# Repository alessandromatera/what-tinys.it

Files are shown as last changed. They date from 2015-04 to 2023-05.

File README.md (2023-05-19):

# "What Tinys.it?"
### A 3D printed LED watch with Atmega328P microcontroller programmed with Arduino

#### The Story
I wanted to build a LED watch with Arduino but, searching on the web, i could not find what i was looking for. So I've decided to build my own.
I wanted to use Attiny85 microcontroller from my board [Tinys](http://www.tinys.it/) but it has only few I/O and can't be used to drive many LEDs. So i decided to use an Atmega328P (the same micro of Arduino UNO board) in TQFP package with 32 pin.

For perfect timing i've used a 32.768 KHz Crystal connected to Xtal pins of Atmega328p running in asynchronous mode. In this way i can use internal 8Mhz oscillator as main clock of the microcontroller and the overflow of timer2 (used for the external crystal) as interrupt for increase the seconds.

Why 32.768Khz Crystal? Because using prescaler to 128 we have 256 Hz, so 1 overflow/sec. It's the most used crystal for watches for this reason.

What about the name? Well, my web site is [Tinys.it](http://www.tinys.it/) :D

#### The Project
I wanted to build a watch with 60 LEDs but to keep the clock size small, i've decide to use only 32 LED (1 LED/100 seconds). But even if the microcontroller has 32 pin, they aren't all I/O: only 25 pins can be used for the 32 LEDs and the button. To drive a larger number of LEDs with few pins i've used the [Charlieplexing Matrix](http://en.wikipedia.org/wiki/Charlieplexing), in this way i can drive 6 LEDs with only 3 Pins. Becouse i can't use two different color of LEDs, to distinguish between hours and minutes, the minutes LED is blinking. 

To reduce battery drain the watch is always in sleep. To show-up the time is needed to press the button.

As the clock hands, the hours LED isn't stay in the same position: is moving a bit, consequently to minutes.

The watch is powered by a 3 Volt CR2032 battery. With this battery the LEDs resistors can be shorted.

#### The Firmware
After setup the timer2 overflow interrupt and the button change-pin interrupt, the microcontroller goes to sleep. Every time the timer2 goes overflow (1 overflow/seconds) the microcontroller wakes up and increase the seconds. 

When the button is pressed for a small period of time, the button's interrupt occur and the time is show up. Instead, if the button is pressed for two seconds, we entering in programming mode, where we can set the time: after all LEDs are turned on, we can release the button and the current hours LED is turned on. Pressing one time the button hours change to the next. To record the current hours you need to press the button for about 2 seconds. After the hours LED is switched off, release the button and the minutes LED is turned on. Like the hours LED push the button to choose the right minutes and then long press to record the minutes. After the minutes LED is turned off, all LEDs is turned on. The corrected time is show up.

#### Upload the sketch
To Upload the firmware i use avr in Mac terminal and an Arduino UNO as ISP programmer. 

To do that follow these steps:

1. Connect the Arduino UNO board to PC or Mac.
2. Select the `ArduinoISP` sketch from `File -> Examples`
3. Upload the sketch to the Arduino UNO board
4. Open the watch sketch
5. Compile the sketch using Arduino IDE
6. Connect the SPI watch pins to Arduino UNO pins in this way:
	* Watch PIN `Reset - JP6` to Arduino PIN `10`
	* Watch PIN `11 - JP3` to Arduino PIN `11`
	* Watch PIN `12 - JP4` to Arduino PIN `12`
	* Watch PIN `13 - JP5` to Arduino PIN `13`
	* Watch PIN `V+ - JP1` to Arduino PIN `+3.3V`
	* Watch PIN `GND - JP2` to Arduino PIN `GND`
7. On Mac terminal (i think is similar for Windows/Linux users) write this
	```
	avrdude -v -v -v -v -cstk500v1 -pm328p  -P/dev/tty.usbmodemfa131 -b19200 -D -e -Ulock:w:0x3F:m -Uefuse:w:0x07:m -Uhfuse:w:0xDE:m -Ulfuse:w:0xE2:m -Uflash:w:/path/of/your/hex/file.hex:i
	```
	
	where:
	 - `tty.usbmodemfa131` is the serial port of Arduino board
	 - `/path/of/your/hex/file.hex` is the path of `.hex` file that can be taken from the Arduino IDE enabling `verbose output` from `Preferences -> Show Verbose output during: -> compilation`
	
All this stuff because i wanted to program the board using SPI not using Arduino bootloader. I Think that the watch can be programmed like an Arduino UNO using the `breadboard 8Mhz internal oscillator` bootloader and soldering two wires to pin `0` and `1` of the watch, but i've not tried it.

I've have used fuses for disabling `BOD` so you need to modify the bootloader of Arduino to do this. (Maybe you can do this in sketch?).

#### The Case
The 3D printed case was realized by my brother Andrea Matera.

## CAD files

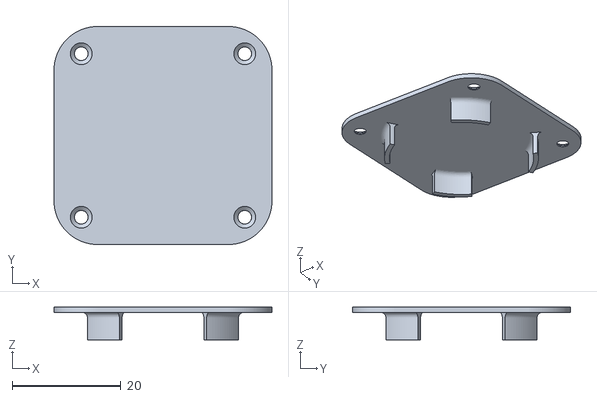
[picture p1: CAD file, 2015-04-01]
Case/tappo.stl
40.0 x 40.0 x 6.00

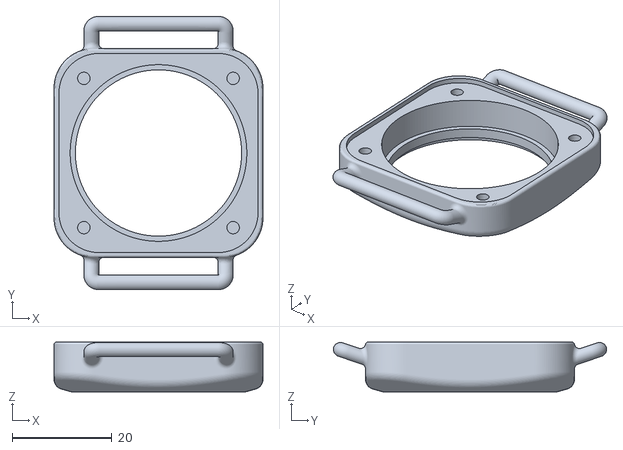
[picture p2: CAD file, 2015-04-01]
Case/Body.stl
42.0 x 54.9 x 10.0

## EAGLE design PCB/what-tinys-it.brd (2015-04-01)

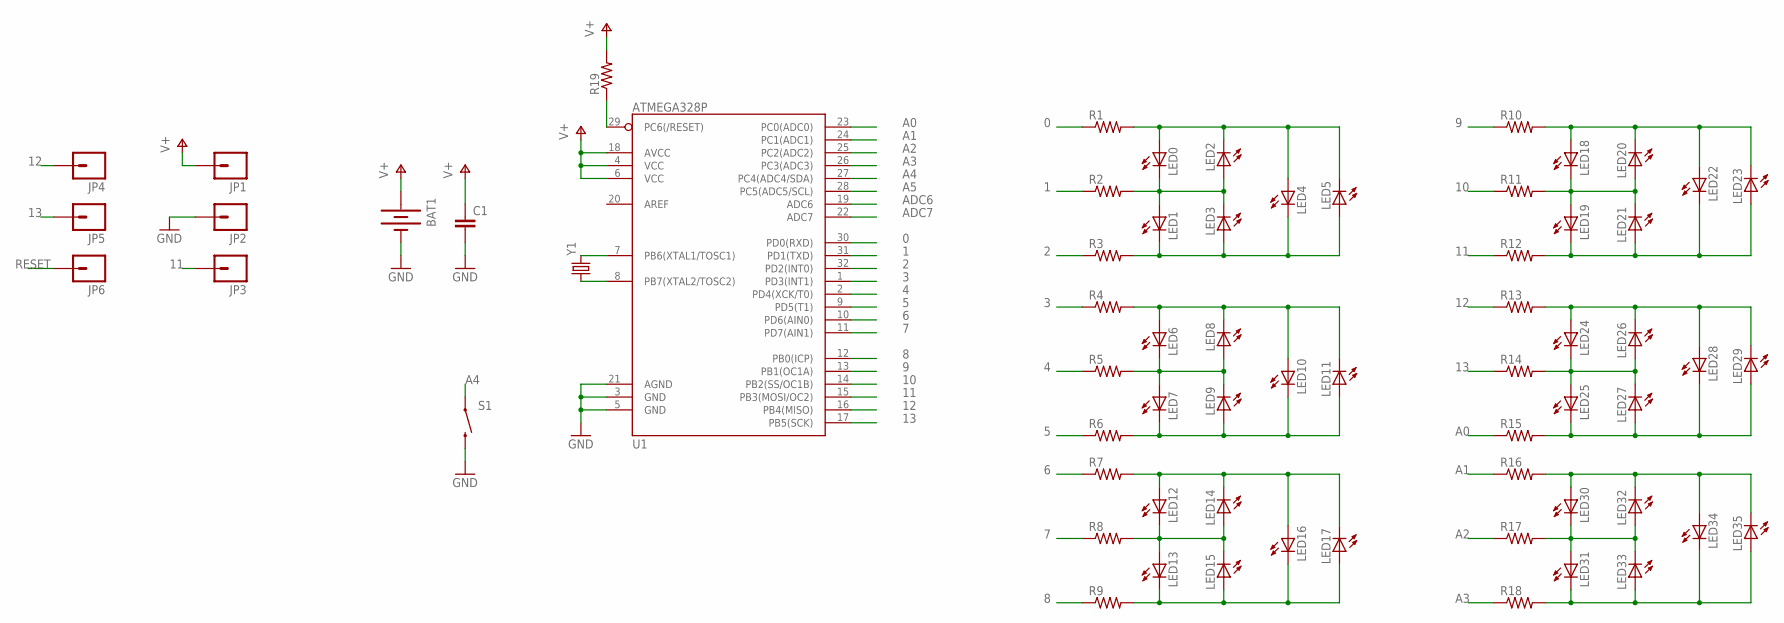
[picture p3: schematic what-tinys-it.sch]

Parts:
BAT1: BATTERY20SMD; BATTCON_20MM
C1: C-EUC0805; C0805
JP1, JP2, JP3, JP4, JP5, JP6: M01SMDNS; 1X01NS
LED0, LED1, LED2, LED3, LED4, LED5, LED6, LED7, LED8, LED9, LED10, LED11, LED12, LED13, LED14, LED15, LED16, LED17, LED18, LED19, LED20, LED21, LED22, LED23, LED24, LED25, LED26, LED27, LED28, LED29, LED30, LED31, LED32, LED33, LED34, LED35: LEDCHIPLED_0805; CHIPLED_0805
R1, R2, R3, R4, R5, R6, R7, R8, R9, R10, R11, R12, R13, R14, R15, R16, R17, R18, R19: RESISTOR0805-RES; 0805
S1: SWITCH-MOMENTARY-2SMD-3; TACTILE_SWITCH_SMD-3
U1: ATMEGA328P; TQFP32-08
Y1: CRYSTAL32-SMD; CRYSTAL-32KHZ-SMD

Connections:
0: R1.1, U1.30 (PD0(RXD))
1: R2.1, U1.31 (PD1(TXD))
2: R3.1, U1.32 (PD2(INT0))
3: R4.1, U1.1 (PD3(INT1))
4: R5.1, U1.2 (PD4(XCK/T0))
5: R6.1, U1.9 (PD5(T1))
6: R7.1, U1.10 (PD6(AIN0))
7: R8.1, U1.11 (PD7(AIN1))
8: R9.1, U1.12 (PB0(ICP))
9: R10.1, U1.13 (PB1(OC1A))
10: R11.1, U1.14 (PB2(SS/OC1B))
11: JP3.1, R12.1, U1.15 (PB3(MOSI/OC2))
12: JP4.1, R13.1, U1.16 (PB4(MISO))
13: JP5.1, R14.1, U1.17 (PB5(SCK))
A0: R15.1, U1.23 (PC0(ADC0))
A1: R16.1, U1.24 (PC1(ADC1))
A2: R17.1, U1.25 (PC2(ADC2))
A3: R18.1, U1.26 (PC3(ADC3))
A4: S1.1, U1.27 (PC4(ADC4/SDA))
A5: U1.28 (PC5(ADC5/SCL))
ADC6: U1.19 (ADC6)
ADC7: U1.22 (ADC7)
GND: BAT1.2 (-), C1.2, JP2.1, S1.4 (2), U1.3 (GND), U1.5 (GND), U1.21 (AGND)
unnamed: LED0.A, LED2.C, LED4.A, LED5.C, R1.2
unnamed: LED6.A, LED8.C, LED10.A, LED11.C, R4.2
unnamed: LED0.C, LED1.A, LED2.A, LED3.C, R2.2
unnamed: LED1.C, LED3.A, LED4.C, LED5.A, R3.2
unnamed: LED12.A, LED14.C, LED16.A, LED17.C, R7.2
unnamed: LED6.C, LED7.A, LED8.A, LED9.C, R5.2
unnamed: LED7.C, LED9.A, LED10.C, LED11.A, R6.2
unnamed: LED18.A, LED20.C, LED22.A, LED23.C, R10.2
unnamed: LED12.C, LED13.A, LED14.A, LED15.C, R8.2
unnamed: LED13.C, LED15.A, LED16.C, LED17.A, R9.2
unnamed: LED18.C, LED19.A, LED20.A, LED21.C, R11.2
unnamed: LED24.A, LED26.C, LED28.A, LED29.C, R13.2
unnamed: LED19.C, LED21.A, LED22.C, LED23.A, R12.2
unnamed: LED24.C, LED25.A, LED26.A, LED27.C, R14.2
unnamed: LED30.A, LED32.C, LED34.A, LED35.C, R16.2
unnamed: U1.7 (PB6(XTAL1/TOSC1)), Y1.X2 (2)
unnamed: LED25.C, LED27.A, LED28.C, LED29.A, R15.2
unnamed: U1.8 (PB7(XTAL2/TOSC2)), Y1.X1 (1)
unnamed: LED30.C, LED31.A, LED32.A, LED33.C, R17.2
unnamed: LED31.C, LED33.A, LED34.C, LED35.A, R18.2
RESET: JP6.1, R19.1, U1.29 (PC6(/RESET))
V+: BAT1.1 (+), C1.1, JP1.1, R19.2, U1.4 (VCC), U1.6 (VCC), U1.18 (AVCC)

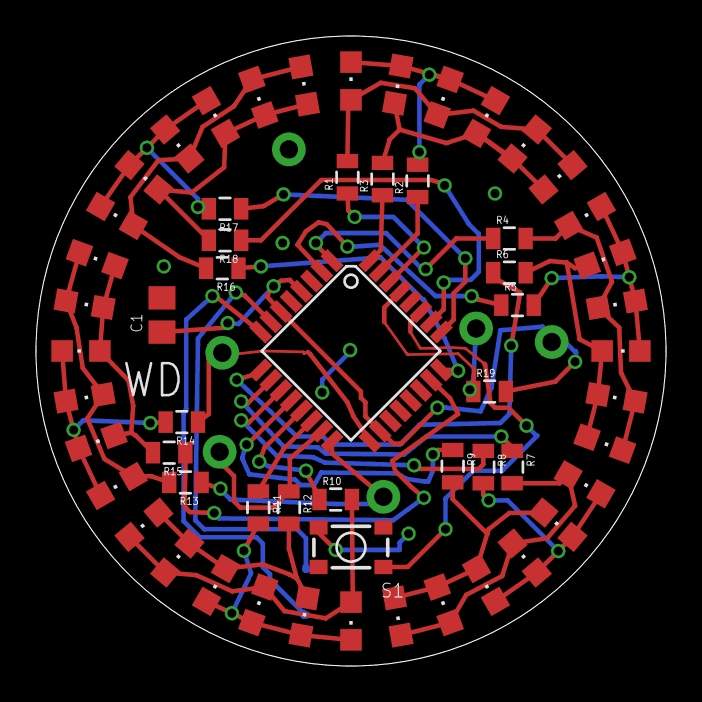
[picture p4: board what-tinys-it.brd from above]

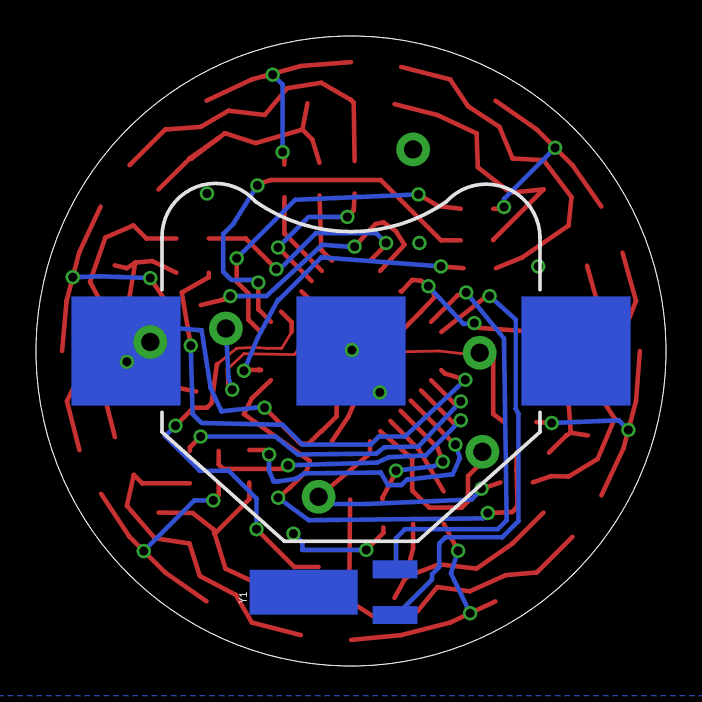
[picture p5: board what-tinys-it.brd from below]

Board: 2 copper layers, 35.0 x 35.0 mm, 66 parts (3 on the bottom side), 42 nets.

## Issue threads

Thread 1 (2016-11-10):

compiling errr

starsx2016, 2016-11-10:
Arduino : 1.6.12 (Mac OS X), Carte : "Arduino Duemilanove or Diecimila, ATmega328"

/Users/starsx/Dropbox/project/what-tinys.it-master/firmware/WhatTinysIt_v_1/WhatTinysIt_v_1.ino: In function 'void setup()':
WhatTinysIt_v_1:49: error: 'button' was not declared in this scope
   pinMode(button, INPUT);
           ^
/Users/starsx/Dropbox/project/what-tinys.it-master/firmware/WhatTinysIt_v_1/WhatTinysIt_v_1.ino: In function 'void loop()':
WhatTinysIt_v_1:77: error: 'button' was not declared in this scope
     while(!digitalRead(button)){
                        ^
/Users/starsx/Dropbox/project/what-tinys.it-master/firmware/WhatTinysIt_v_1/WhatTinysIt_v_1.ino: In function 'void setClock()':
WhatTinysIt_v_1:156: error: 'button' was not declared in this scope
   while(!digitalRead(button)){
                      ^
WhatTinysIt_v_1:178: error: 'button' was not declared in this scope
     while(!digitalRead(button)){
                        ^
WhatTinysIt_v_1:199: error: 'button' was not declared in this scope
       while(!digitalRead(button)){
                          ^
WhatTinysIt_v_1:212: error: 'button' was not declared in this scope
     while(!digitalRead(button)){
                        ^
WhatTinysIt_v_1:231: error: 'button' was not declared in this scope
       while(!digitalRead(button)){
                          ^
exit status 1
'button' was not declared in this scope

alessandromatera, 2016-11-10:
Try this:

At the top of the sketch, after define declarations, write:

Int button = A4;

Instead
#define A4 button

starsx2016, 2016-11-10:
thank you

Closed 2023-05-19.

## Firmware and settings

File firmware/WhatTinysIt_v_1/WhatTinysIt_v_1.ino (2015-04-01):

#include <avr/sleep.h>
#include <avr/power.h>
#include <avr/interrupt.h>

#define A4 button

unsigned int seconds = 0;
unsigned int hours = 0;

boolean button_interrupt = false; //boolean to let you know when interrupt button is occurred

int setupPeriod = 2; //hold down button for this period in seconds to enter in programming mode

//overflow interrupt from 32.768Khz Crystal every 1 sec
ISR(TIMER2_OVF_vect){
  //increase the seconds
  seconds++;
  //if seconds is over 3600, we increase the hours
  if (seconds > 3600) {
    seconds = 0;
    hours++;
    //if hours is over 11 come back to zero
    if (hours > 11) {
      hours = 0;
    }
  }
}

//pin-change interrupt from button
ISR(PCINT1_vect){
  //disable interrupt button to not start another interrupt
  bitClear(PCMSK1,PCINT12);
  button_interrupt = true;
}


void setup() {
  TIMSK2  = 0; //stop timer interrupt
  TCCR2A = 0; // this stops the timer
  TCCR2B = 0;  // this stops the timer
  TCNT2 = 0;  // reset the timer2 counter

  //Enable asynchronous mode
  bitSet(ASSR, AS2); //set TMR2 to work in asynchronous mode
  TCCR2B = bit(CS22) | bit(CS20); // prescaler 128 -> 256 Hz = 1 overflow/sec
  bitSet(TIMSK2, TOIE2); //eable overflow interrupt for tmr2

    //setup pin-change interrupt for button
  pinMode(button, INPUT);
  digitalWrite(button, HIGH);//enable pullup resistor
  bitSet(PCMSK1,PCINT12); //enable pinchange for pin A4
  bitSet(PCICR,PCIE1); //enable interrupt button

  //disabling all unnecessary peripherals to reduce power
  ADCSRA &= ~bit(ADEN); //disable ADC
  power_adc_disable(); // disable ADC converter
  power_spi_disable(); // disable SPI
  power_usart0_disable();// disable Serial (USART)
  power_timer1_disable();// disable Timer 1
  power_twi_disable(); // disable TWI (I2C)

}

void loop() {
  //if we press the button the pin-change interrupt occur
  //then if we fast press the button show up the time
  //else, if we press the button for "setupPeriod" seconds we
  //enter in programming mode and then set the time
  if (button_interrupt){
    button_interrupt = false; //resetting our boolean flag
    
    //store and calculating the pressing time of the button
    int oldSeconds = seconds;
    int buttonSeconds = 0;
    
    //while the button is pressed we count the pressing time
    while(!digitalRead(button)){
      buttonSeconds = seconds-oldSeconds;
      if (buttonSeconds > setupPeriod){ //if we have pressed for over setupPeriod seconds
        setClock();  //enter in programming mode
      }
    }
    
    //show up the time
    showTime();

    bitSet(PCMSK1,PCINT12); //enable interrupt button
  }

  goSleep(); //go power save
}


void showTime(){

  int showPeriod = 4000; //showing time period in milliseconds
  int blinkingPeriod = 500; //blinking period for minutesLED in milliseconds

  int hoursLED = calculateHoursLED(hours, seconds);
  int minutesLED = calculateMinutesLED(seconds);

  //animation light game
  int oldSeconds = seconds;
  int i_led_game = hoursLED+1;
  if (i_led_game > 35)
    i_led_game = 0;
  boolean minutesLEDfired = false;
  unsigned long previouosMillis_animation = millis();
  while(i_led_game != hoursLED){
    changeLED(hoursLED, 1); //turn On hours LED
    changeLED(hoursLED, 0); //turn off hoursLED for multiplexing

    changeLED(i_led_game, 1); //turn on game LED
    changeLED(i_led_game, 0);

    //if LED game pass on minutes LED turn on minutesLED and stay on
    if(i_led_game == minutesLED || minutesLEDfired){ 
      minutesLEDfired = true;
      changeLED(minutesLED, 1); //turn On minutes LED
      changeLED(minutesLED, 0);
    }

    if ((millis() - previouosMillis_animation) > 10){ //every 10 ms change the game LED
      previouosMillis_animation = millis();
      i_led_game++;
      if (i_led_game > 35)
        i_led_game = 0;
    }
  }


  unsigned long currentMillis = millis();
  unsigned long previousMillis = currentMillis;
  unsigned long previousMillis_blinking = currentMillis;
  boolean minutesLEDstate = true;

  //show-up hours and seconds
  while ((millis() - previousMillis) < showPeriod) {

    changeLED(hoursLED, 1); //turn On hours LED
    changeLED(hoursLED, 0); //turn Off hours LED
    if ((millis() - previousMillis_blinking) >= blinkingPeriod) { //blink minute LED
      previousMillis_blinking = millis();
      minutesLEDstate = !minutesLEDstate;
    }
    changeLED(minutesLED, minutesLEDstate); //turn On/Off minutes LED
    changeLED(minutesLED, 0); //turn Off minutes LED
  }
}

//change hours and minutes -> programming mode
void setClock(){

  //while the button is pressed we turn on all LED
  //to let you know that we are in programming mode
  while(!digitalRead(button)){
    for (int i = 0; i <36; i++){
      changeLED(i, 1);
      changeLED(i, 0);
    }
  }


  int oldSeconds = seconds; //variable for button timing

  boolean hourSetted = false; //boolean for exit hours programming mode
  int hoursToSet = hours; //store hours
  if (seconds>=3550) //if seconds is higher than 3550 we turn on next hour because LED 0 is turned on
    hoursToSet++;
  int hoursLED = calculateHoursLED(hoursToSet, 0); //calculatin which hoursLED need to turnON
  changeLED(hoursLED, 1); //turn on the hoursLED
  while(!hourSetted){ //while hours are not setted
    boolean buttonPressed = false;
    oldSeconds = seconds;

    //if we press the button for small period of time, we change the hours
    //if we press for long time (setupPeriod) we set the hours and then go to setting minutes
    while(!digitalRead(button)){ 
      buttonPressed = true;
      delay(100);
      int buttonSeconds = seconds-oldSeconds;
      //setting hours
      if (buttonSeconds > setupPeriod){
        hourSetted = true;
        changeLED(hoursLED, 0);
        hours = hoursToSet; //set the hours
        while(!digitalRead(button)){
        }
      }
    }
    //changing hours
    if (!hourSetted && buttonPressed){
      changeLED(hoursLED, 0);
      hoursToSet++;
      if (hoursToSet>11)
        hoursToSet = 0;
      hoursLED = calculateHoursLED(hoursToSet, 0);
      changeLED(hoursLED, 1);
      while(!digitalRead(button)){
      }
    }
  }

  //we do the same things for minutes programming
  boolean minutesSetted = false;
  int secondsToSet = calculateMinutesLED(seconds)*100; //calculate seconds in relation of minutesLED turned on
  int minutesLED = calculateMinutesLED(secondsToSet);
  changeLED(minutesLED, 1);
  while(!minutesSetted){
    boolean buttonPressed = false;
    oldSeconds = seconds;
    while(!digitalRead(button)){
      buttonPressed = true;
      delay(100);
      int buttonSeconds = seconds-oldSeconds;
      if (buttonSeconds > setupPeriod){
        minutesSetted = true;
        changeLED(minutesLED, 0);
        seconds = secondsToSet;
        while(!digitalRead(button)){
        }
      }
    }
    if (!minutesSetted && buttonPressed){
      changeLED(minutesLED, 0);
      secondsToSet+=100;
      if (secondsToSet>3500)
        secondsToSet = 0;
      minutesLED = calculateMinutesLED(secondsToSet);
      changeLED(minutesLED, 1);
      while(!digitalRead(button)){
      }
    }
  }

  //now we can exit from programming mode.
  //turn on all LED for 1 second.
  oldSeconds = seconds;
  while(seconds-oldSeconds < 1){
    for (int i = 0; i <36; i++){
      changeLED(i, 1);
      changeLED(i, 0);
    }
  }

}



//in this funciton we pass the hours and seconds then return the number of the hours led
// that must be turn on
int calculateHoursLED(int Hours, int Seconds){
  //determine which hours LED to turn on
  int hoursLED = Hours + Hours * 2;
  if (Seconds >= 1200 && Seconds < 2400){
    hoursLED++;
  }
  else if (Seconds >= 2400 && Seconds < 3550){
    hoursLED+=2;
  }
  //if seconds is higher than 3550 we need to turn on the minutes LED 0 and, as a result, the next hours.
  else if (Seconds >= 3550) 
    //hoursLED = (hours+1) + (hours+1) * 2;
    hoursLED+=3;
  if (hoursLED > 35)
    hoursLED = 0;

  return hoursLED;
}


//in this funciton we pass the seconds and return the number of the minutes led
// that must be turn on
int calculateMinutesLED(int Seconds){
  int minutesLED = 0;
  //determine which minutes LED to blinking
  double minutesLED_count = Seconds / 100; //example: 156/100 = 1,56
  int minutesLED_count_int = minutesLED_count; // example: 1
  int minutesLED_count_dec = Seconds - (minutesLED_count_int * 100); //example: 156 - 100 = 56
  if (minutesLED_count_dec >= 50){ //if decimal is higher than 50
    minutesLED = minutesLED_count_int + 1; //turn on the next minutes LED
    if (minutesLED > 35) //if the minutesLED is higher than 35
        minutesLED = 0;  //we turn on the LED 0
  }
  else
    minutesLED = minutesLED_count_int; 

  return minutesLED;
}

//now we go sleep disabling all unnecessary peripherals
void goSleep() {
  power_timer0_disable();// disable Timer 0
  set_sleep_mode(SLEEP_MODE_PWR_SAVE);
  
  //as explained in the datasheet, after and before the sleep mode, with timer 2 in asyncrhonous mode, we
  //need to write anything to this register and then wait for those registers flag go to zero.
  OCR2A = 0xFF;
  while (ASSR & (_BV(TCN2UB) | _BV(TCR2AUB) | _BV(TCR2BUB) | _BV(OCR2AUB) | _BV(OCR2BUB))) {
  }
  
  //go sleep
  sleep_mode();
  
  //the same as above
  OCR2A = 0xFF;
  while (ASSR & (_BV(TCN2UB) | _BV(TCR2AUB) | _BV(TCR2BUB) | _BV(OCR2AUB) | _BV(OCR2BUB))) {
  }
  
  power_timer0_enable();// re-enable Timer 0
}


//change LED status (on/off) to the charlieplexing matrix.
// we pass the LED number and the state (1/0 = high/low)
void changeLED(int led, boolean state) {
  int pinA, pinB, pinC;

  if (led >= 0 && led <= 5) {
    pinA = 0;
    pinB = 1;
    pinC = 2;
  }
  else if (led >= 6 && led <= 11) {
    pinA = 3;
    pinB = 4;
    pinC = 5;
    led = led - 6;
  }
  else if (led >= 12 && led <= 17) {
    pinA = 6;
    pinB = 7;
    pinC = 8;
    led = led - 12;
  }
  else if (led >= 13 && led <= 23) {
    pinA = 9;
    pinB = 10;
    pinC = 11;
    led = led - 18;
  }
  else if (led >= 24 && led <= 29) {
    pinA = 12;
    pinB = 13;
    pinC = A0;
    led = led - 24;
  }
  else if (led >= 30 && led <= 35) {
    pinA = A1;
    pinB = A2;
    pinC = A3;
    led = led - 30;
  }

  switch (led) {
  case 0:
    pinMode(pinA, OUTPUT);
    pinMode(pinB, OUTPUT);
    pinMode(pinC, INPUT);

    if (state) {
      digitalWrite(pinA, HIGH);
      digitalWrite(pinB, LOW);
    }
    else {
      digitalWrite(pinA, LOW);
      digitalWrite(pinB, LOW);
    }
    break;


  case 1:
    pinMode(pinA, INPUT);
    pinMode(pinB, OUTPUT);
    pinMode(pinC, OUTPUT);

    if (state) {
      digitalWrite(pinB, HIGH);
      digitalWrite(pinC, LOW);
    }
    else {
      digitalWrite(pinB, LOW);
      digitalWrite(pinC, LOW);
    }
    break;

  case 2:
    pinMode(pinA, OUTPUT);
    pinMode(pinB, OUTPUT);
    pinMode(pinC, INPUT);

    if (state) {
      digitalWrite(pinB, HIGH);
      digitalWrite(pinA, LOW);
    }
    else {
      digitalWrite(pinB, LOW);
      digitalWrite(pinA, LOW);
    }
    break;

  case 3:
    pinMode(pinA, INPUT);
    pinMode(pinB, OUTPUT);
    pinMode(pinC, OUTPUT);

    if (state) {
      digitalWrite(pinC, HIGH);
      digitalWrite(pinB, LOW);
    }
    else {
      digitalWrite(pinC, LOW);
      digitalWrite(pinB, LOW);
    }
    break;

  case 4:
    pinMode(pinA, OUTPUT);
    pinMode(pinB, INPUT);
    pinMode(pinC, OUTPUT);

    if (state) {
      digitalWrite(pinA, HIGH);
      digitalWrite(pinC, LOW);
    }
    else {
      digitalWrite(pinA, LOW);
      digitalWrite(pinC, LOW);
    }
    break;

  case 5:
    pinMode(pinA, OUTPUT);
    pinMode(pinB, INPUT);
    pinMode(pinC, OUTPUT);

    if (state) {
      digitalWrite(pinC, HIGH);
      digitalWrite(pinA, LOW);
    }
    else {
      digitalWrite(pinC, LOW);
      digitalWrite(pinA, LOW);
    }
    break;

  }
}

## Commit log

2015-04-01 Sketch
    Arduino Sketch file
2015-04-01 PCB and schematic
    [what-tinys-it.brd, what-tinys-it.sch]
2015-04-01 3D printed Case
    [Body.stl, tappo.stl]

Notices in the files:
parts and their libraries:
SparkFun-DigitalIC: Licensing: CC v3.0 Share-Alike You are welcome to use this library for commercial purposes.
